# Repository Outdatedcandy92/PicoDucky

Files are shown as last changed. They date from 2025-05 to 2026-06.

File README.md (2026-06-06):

# PicoDucky V2.2

PicoDucky Version 2.2 is a minimalist, USB-stick-style RP2350 board designed for use as a security key or rubber ducky.

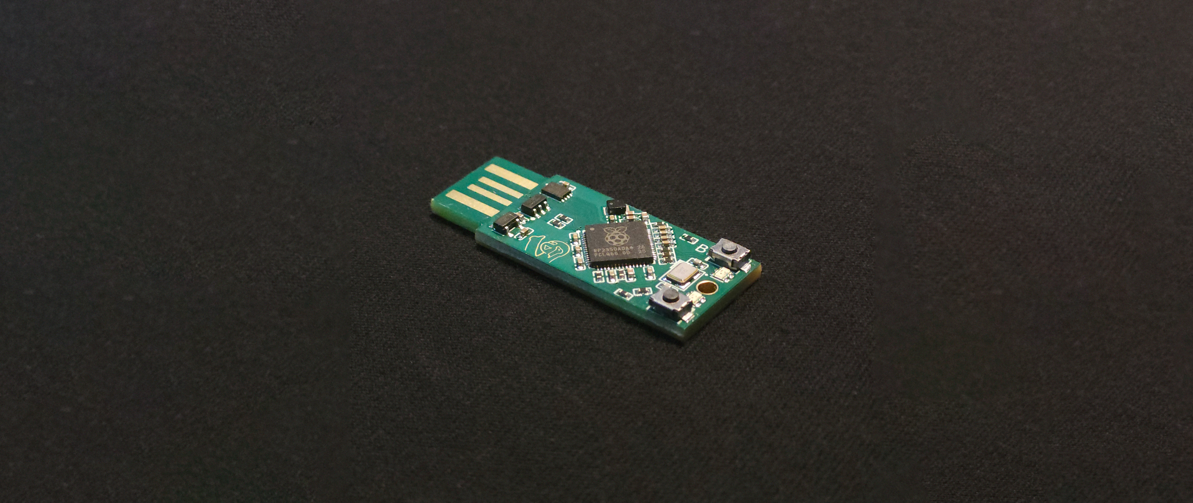
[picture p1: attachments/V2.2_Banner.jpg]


All source files for this board are located in `/src/V2.2`.

## Table of Contents

- [Overview](#picoducky-v2.2)
- [Quick Start](#quick-start)
- [Hardware](#hardware)
	- [Pinout](#pinout)
	- [Schematic](#schematic)
	- [PCB](#pcb)
	- [BOM/Reproduction](#bom/reproduction)
- [Firmware](#firmware)
- [Changelog](#changelog)
- [License](#license)

## Quick Start

To get started and use it as a security key
1. Hold the boot button on the board while plugging in the USB-C cable (the button has a `B` mark beside it).
2. The board will appear as a mass storage device.
3. Drag and drop the `picofido.uf2` file from `/firmware` onto the device.

The board will reboot, and the LEDs on the board should blink. It's now ready to be used as a FIDO security key.

You can head over to [webauthn.io](https://webauthn.io/) to test out your key.

Additional documentation can be found on [picoducky.rudymakes.com/docs](https://picoducky.rudymakes.com/docs)

## Hardware

### Pinout

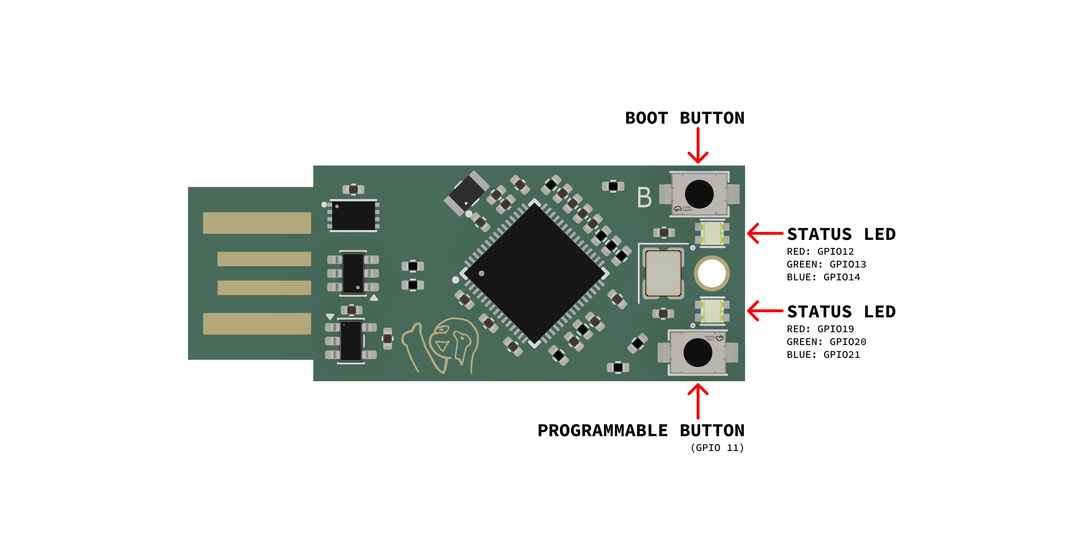
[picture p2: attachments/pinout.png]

### Schematic

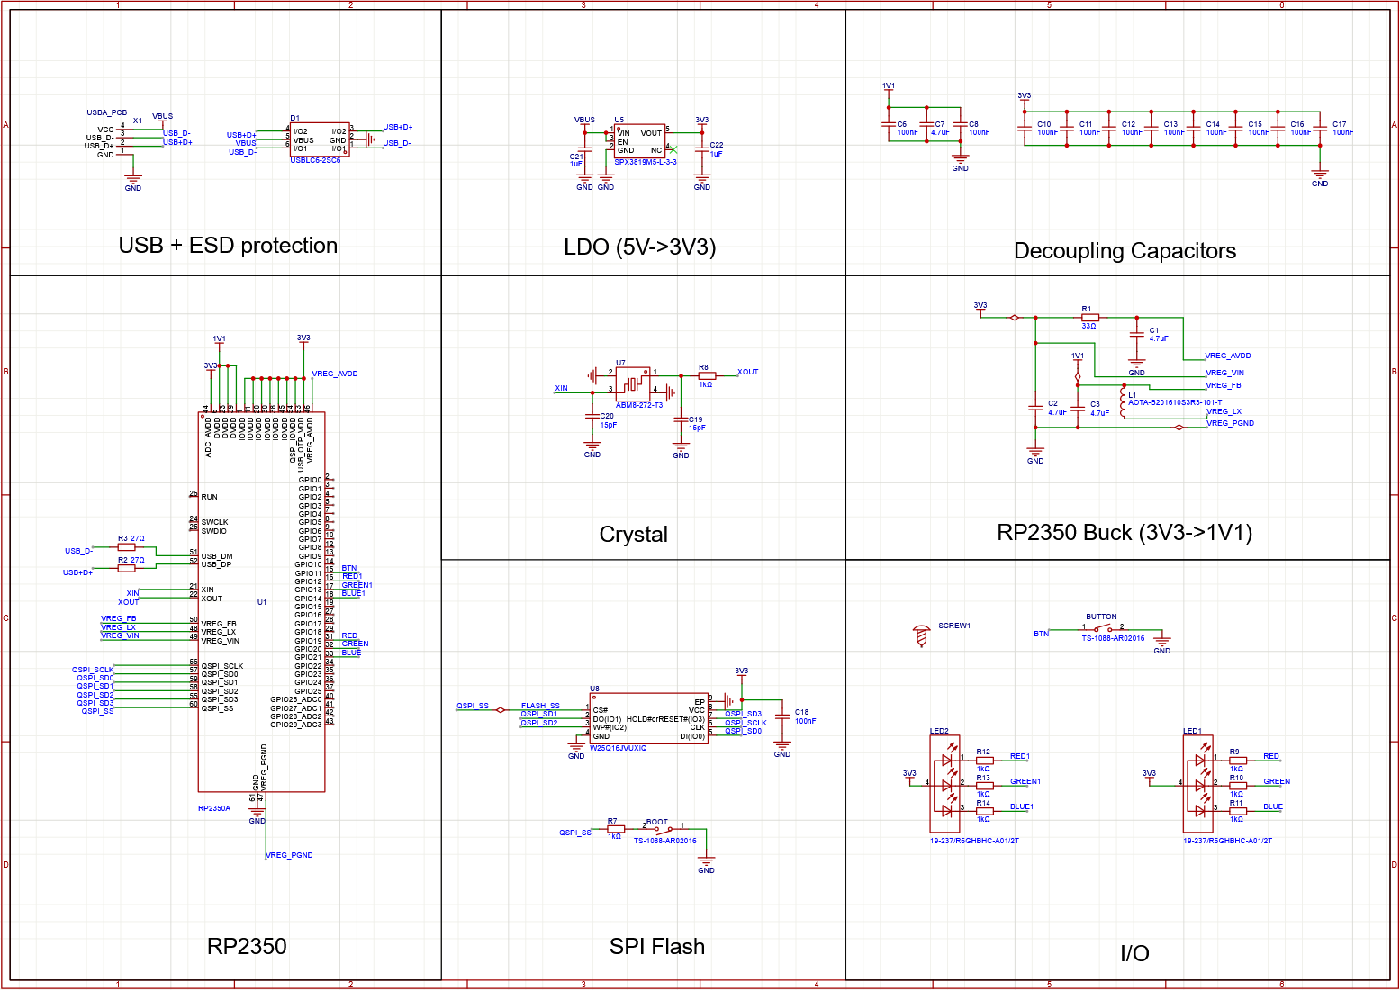
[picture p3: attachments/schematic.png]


### PCB

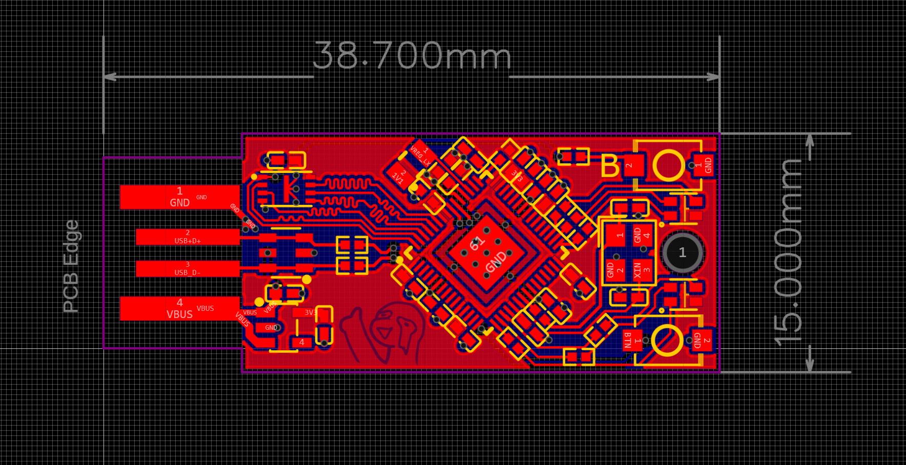
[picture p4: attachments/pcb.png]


### BOM/Reproduction

The BOM and gerber files can be found under `/hardware/{revision}/production`

If you plan on ordering the board make sure to set your board thickness to 2.0mm to ensure it fits snugly in a USB A port. Getting ENIG finish is also recommended as it doesn't oxidize and wears less over time.

Do note that having 2.0mm and ENIG together will lead to high setup fees from your PCB fab and will be expensive. For reference getting the minimum order quantity of 5 PCBs and 2 assembled PCBs from JLCPCB with 2.0mm thickness and ENIG costs around $100.

## Firmware

This board uses [Pico Fido](https://github.com/polhenarejos/pico-fido) by [Pol Henarejos](https://github.com/polhenarejos) with slight modifications such as updating the status LED pin number for the board.

## Changelog

#### V2.2
- Switched down the external flash from 8mb to 2mb to optimize cost
#### V2.1
- Switched down to a 8mb flash for smaller footprint
- Added a 2mm hole for keychains
- Switched back to using 2 RGB LEDs
- Optimized layout and routing compared to previous versions
#### V2.0
- Switched to the RP2350
- Used smaller SOT-23-5 LDO
- Switched to using 2 bigger buttons
- 1 Green Status LED
- Added ESD protection on USB lines
#### V1.0
First ever version
- Used the RP2040
- 16mb external flash
- Chonky SOT-223 footprint LDO
- 3 tiny buttons (very hard to click)
- 2 RBG LEDs

---
## License

This project is licensed under the CERN Open Hardware Licence Version 2 Weakly Reciprocal [(CERN OHL W)](LICENSE.txt)

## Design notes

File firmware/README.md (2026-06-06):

# PicoDucky Documentation

The `pico-fido` folder includes the source code for the modified version of PicoFIDO that the PicoDucky is running.

Additional documentation can be found on [picoducky.rudymakes.com/docs](https://picoducky.rudymakes.com/docs)

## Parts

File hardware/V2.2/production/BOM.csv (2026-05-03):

No. | Quantity | Footprint | Value | Device | LCSC Stock | LCSC Price | JLCPCB Stock | JLCPCB Price | Supplier Part | Manufacturer Part
1 | 1 | USBA_PCB |  | USBA_PCB |  | 2.6475
2 | 1 | SW-SMD_L3.9-W3.0-P4.45 |  | TS-1088-AR02016 |  |  | 582292 | 0.0083 | C720477 | TS-1088-AR02016
3 | 1 | C0402 | 4.7uF | CL05A475MP5NRNC |  |  | 2960347 | 0.0009 | C23733 | CL05A475MP5NRNC
4 | 1 | C0402 | 100nF | CL05B104KO5NNNC |  |  | 20013117 | 0.0002 | C1525 | CL05B104KO5NNNC
5 | 1 | C0402 | 1uF | CL05A105KA5NQNC |  |  | 8734328 | 0.0006 | C52923 | CL05A105KA5NQNC
6 | 1 | SOT-23-6_L2.9-W1.6-P0.95-LS2.8-BL |  | USBLC6-2SC6_C2687116 |  |  | 251847 | 0.0067 | C2687116 | USBLC6-2SC6
7 | 1 | IND-SMD_L2.0-W1.6_AOTA-B201610S3R3-101-T |  | AOTA-B201610S3R3-101-T |  |  | 9385 | 0.0424 | C42411119 | AOTA-B201610S3R3-101-T
8 | 1 | R0402 | 33Ω | 0402WGF330JTCE |  |  | 5209402 | 0.0002 | C25105 | 0402WGF330JTCE
9 | 1 | R0402 | 1kΩ | 0402WGF1001TCE |  |  | 12688834 | 0.0002 | C11702 | 0402WGF1001TCE
10 | 1 | SOT-23-5_L3.0-W1.6-P0.95-LS2.8-BR |  | SPX3819M5-L-3-3 |  |  | 66147 | 0.0157 | C20617301 | SPX3819M5-L-3-3
11 | 1 | QFN-60_L7.0-W7.0-P0.40-TL-EP3.4 |  | RP2350A_C42411118 |  |  | 3597 | 0.1854 | C42411118 | RP2350A
12 | 1 | C0402 | 15pF | 0402CG150J500NT |  |  | 1496521 | 0.0002 | C1548 | 0402CG150J500NT
13 | 1 | CRYSTAL-SMD_4P-L3.2-W2.5-BL |  | ABM8-272-T3_C20625731 |  |  | 13844 | 0.0431 | C20625731 | ABM8-272-T3
14 | 1 | LED-ARRAY-SMD_4P-L1.6-W1.6-BL_1 |  | 19-237/R6GHBHC-A01/2T |  |  | 41805 | 0.0093 | C60105 | 19-237/R6GHBHC-A01/2T
15 | 1 | Screw-Hole-M2 |  | Screw-Hole-M2 |  | 2.6475
16 | 1 | R0402 | 27Ω | 0402WGF270JTCE |  |  | 344663 | 0.0002 | C25100 | 0402WGF270JTCE
17 | 1 | USON-8_L3.0-W2.0-P0.50-BL-EP |  | W25Q16JVUXIQ |  |  | 2 | 0.1047 | C2843335 | W25Q16JVUXIQ

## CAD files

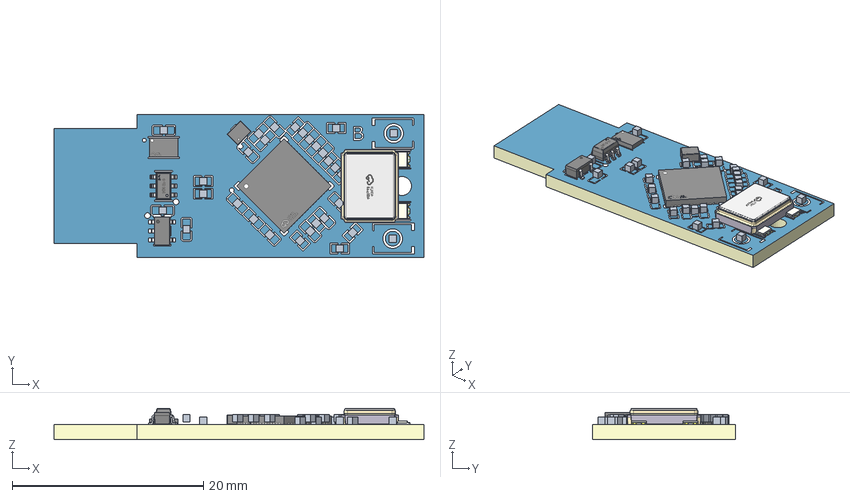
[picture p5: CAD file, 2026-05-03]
hardware/V2.2/CAD/3D.step
38.7 x 15.0 x 3.28 mm
Board~NZN2
TopCopper~NZN2
BottomCopper~NZN2
TopSilkscreen~NZN2
TopFpcStiffener~NZN2
BottomFpcStiffener~NZN2
SOT-23-6_L2.9-W1.6-P0.95-LS2.8-BL~SOT-23-6_ L2.9-W1.6-H1.5-LS2.8-P0.95~NZN2
CRYSTAL-SMD_4P-L3.2-W2.5-BL~CRYSTAL-SMD_4P-L3.2-W2.5-BL~NZN2
R3~R0402~R0402_L1.0-W0.5-H0.4~NZN2 x 11
BUTTON~SW-SMD_L3.9-W3.0-P4.45~SW-SMD_L3.9-W2.9-H2.0-LS4.8~NZN2 x 2
C20~C0402~C0402_L1.0-W0.5-H0.5~NZN2 x 19
LED-ARRAY-SMD_4P-L1.6-W1.6-BL_1~LED-ARRAY-SMD_4P-L1.6-W1.6_ EAST1616RGBB6~NZN2 x 2
SOT-23-5_L3.0-W1.6-P0.95-LS2.8-BR~SOT-23-5_ L3.0-W1.6-P0.95-LS2.8-BR~NZN2
USON-8_L3.0-W2.0-P0.50-BL-EP~USON-8_L2.0-W3.0-P0.50-TL-EP~NZN2
IND-SMD_L2.0-W1.6_AOTA-B201610S3R3-101-T~IND-SMD_L2.0-W1.6_ AOTA-B201610S3R3-101-T~NZN2
QFN-60_L7.0-W7.0-P0.40-TL-EP3.4~QFN-60_L7.0-W7.0-P0.40-TL-EP_ XU316-1024~NZN2

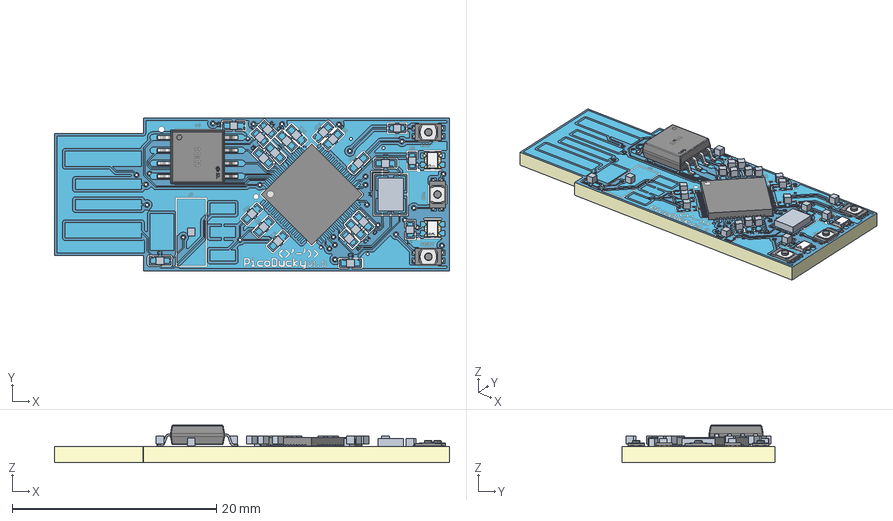
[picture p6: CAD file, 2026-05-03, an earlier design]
hardware/V1.0/CAD/PCB.step
38.7 x 15.0 x 3.68 mm
Board~82VG
TopCopper~82VG
BottomCopper~82VG
TopSilkscreen~82VG
TopFpcStiffener~82VG
BottomFpcStiffener~82VG
R7~R0402~R0402_L1.0-W0.5-H0.4~82VG x 6
C8~C0402~C0402_L1.0-W0.5-H0.5~82VG x 16
CRYSTAL-SMD_4P-L3.2-W2.5-BL~CRYSTAL-SMD_4P-L3.2-W2.5-BL~82VG
SOT-223-3_L6.5-W3.4-P2.30-LS7.0-BR~SOT-223-4P_ L6.5-W3.5-H1.6-LS7.0-P2.30~82VG
SW-SMD_4P-L2.6-W1.6-P0.75-LS3.0~SW-SMD_4P-L2.6-W1.6-P0.75-LS3.0~82VG x 3
LED-ARRAY-SMD_4P-L1.6-W1.6-BL-CW~LED-SMD-4P_L1.6-W1.6-H0.4-LS1.6~82VG x 2
SOIC-8_L5.3-W5.3-P1.27-LS8.0-BL~SOIC-8_L5.3-W5.3-H1.9-LS7.9-P1.27~82VG
LQFN-56_L7.0-W7.0-P0.4-EP~QFN-56_L7.0-W7.0-P0.40-TL-EP4.0~82VG

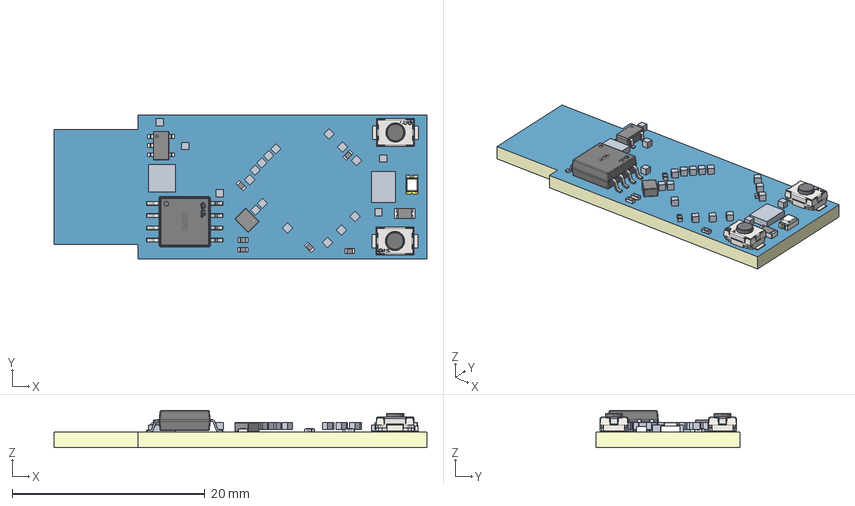
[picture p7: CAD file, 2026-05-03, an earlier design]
hardware/V2.0/CAD/3D.step
38.7 x 15.0 x 3.85 mm
Board~88uZ
TopCopper~88uZ
BottomCopper~88uZ
TopFpcStiffener~88uZ
BottomFpcStiffener~88uZ
C22~C0402~C0402_L1.0-W0.5-H0.5~88uZ x 19
LED0805-R-RD~LED0805-RD~88uZ
R0603~R0603~88uZ
SOT-23-6_L2.9-W1.6-P0.95-LS2.8-BL~SOT-23-6_ L2.9-W1.6-H1.5-LS2.8-P0.95~88uZ
CRYSTAL-SMD_4P-L3.2-W2.5-BL~CRYSTAL-SMD_4P-L3.2-W2.5-BL~88uZ
IND-SMD_L2.0-W1.6_AOTA-B201610S3R3-101-T~IND-SMD_L2.0-W1.6_ AOTA-B201610S3R3-101-T~88uZ
SW-SMD_L3.9-W3.0-P4.45~SW-SMD_L3.9-W2.9-H2.0-LS4.8~88uZ x 2
R0402~R0402_L1.0-W0.5-H0.4~88uZ x 6
SOT-23-5_L3.0-W1.6-P0.95-LS2.8-BR~SOT-23-5_ L3.0-W1.6-P0.95-LS2.8-BR~88uZ
SOP-8_L5.3-W5.3-P1.27-LS8.0-BL~SOP-8_L5.2-W5.3-H2.1-LS7.9-P1.27~88uZ

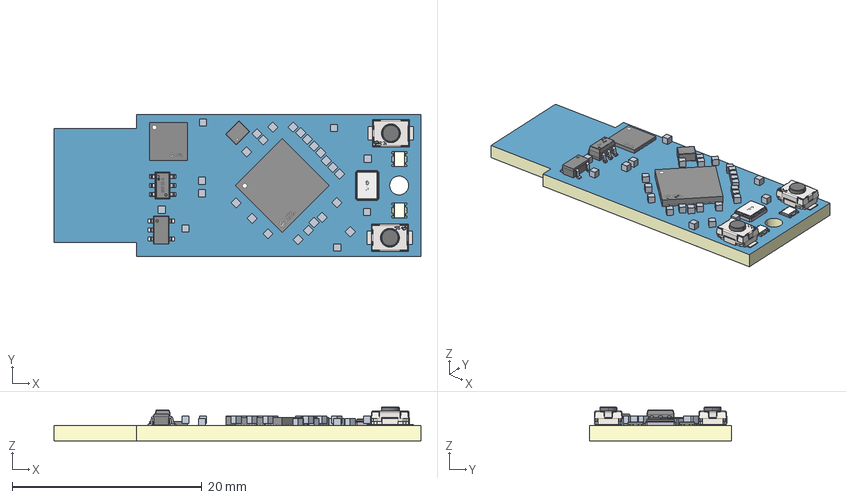
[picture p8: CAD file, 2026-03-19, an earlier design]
hardware/V2.1/CAD/3D.step
38.7 x 15.0 x 3.55 mm
Board~sNAA
TopCopper~sNAA
BottomCopper~sNAA
TopFpcStiffener~sNAA
BottomFpcStiffener~sNAA
SW-SMD_L3.9-W3.0-P4.45~SW-SMD_L3.9-W2.9-H2.0-LS4.8~sNAA x 2
C20~C0402~C0402_L1.0-W0.5-H0.5~sNAA x 19
R3~R0402~R0402_L1.0-W0.5-H0.4~sNAA x 11
SOT-23-6_L2.9-W1.6-P0.95-LS2.8-BL~SOT-23-6_ L2.9-W1.6-H1.5-LS2.8-P0.95~sNAA
IND-SMD_L2.0-W1.6_AOTA-B201610S3R3-101-T~IND-SMD_L2.0-W1.6_ AOTA-B201610S3R3-101-T~sNAA
XSON-8_L4.0-W4.0-P0.80-TL-EP~XSON-8_L4.0-W4.0-P0.80-TL-EP~sNAA
LED-ARRAY-SMD_4P-L1.6-W1.6-BL_1~LED-ARRAY-SMD_4P-L1.6-W1.6_ EAST1616RGBB6~sNAA x 2
CRYSTAL-SMD_4P-L3.2-W2.5-BL~CRYSTAL-SMD_4P-L3.2-W2.5-BL~sNAA
QFN-60_L7.0-W7.0-P0.40-TL-EP3.4~QFN-60_L7.0-W7.0-P0.40-TL-EP_ XU316-1024~sNAA
SOT-23-5_L3.0-W1.6-P0.95-LS2.8-BR~SOT-23-5_ L3.0-W1.6-P0.95-LS2.8-BR~sNAA

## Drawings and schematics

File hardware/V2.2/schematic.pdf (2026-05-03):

USB + ESD protection | LDO (5V->3V3) | Decoupling Capacitors

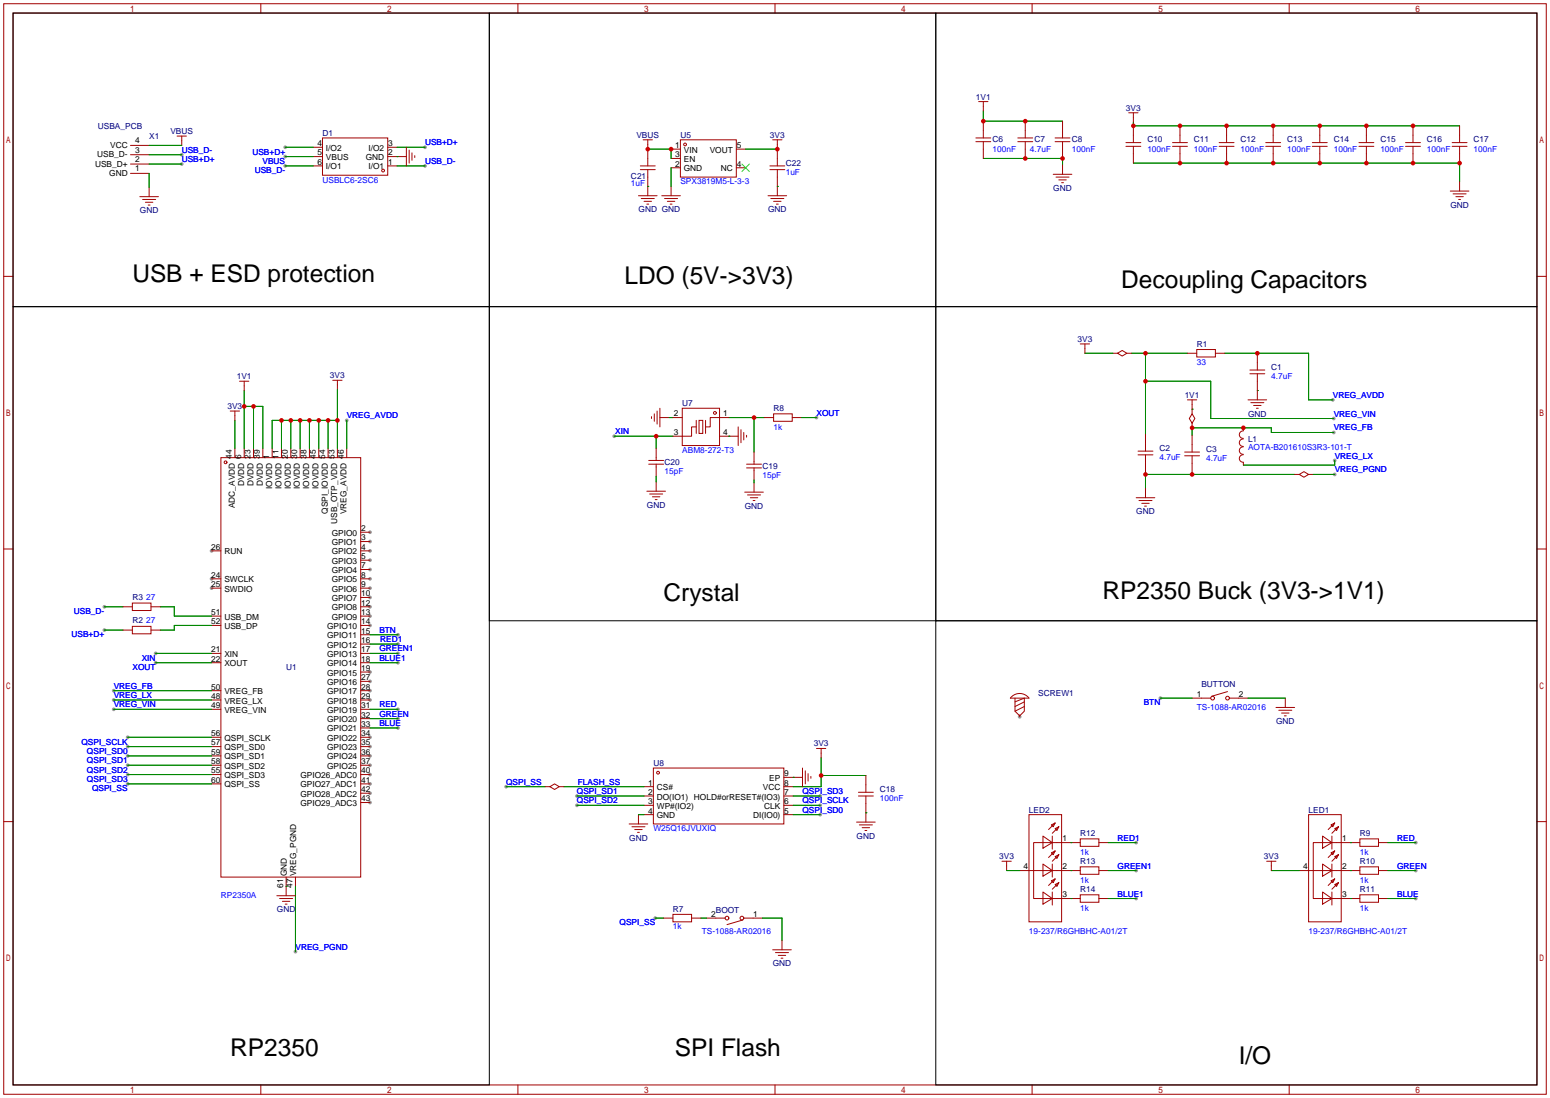
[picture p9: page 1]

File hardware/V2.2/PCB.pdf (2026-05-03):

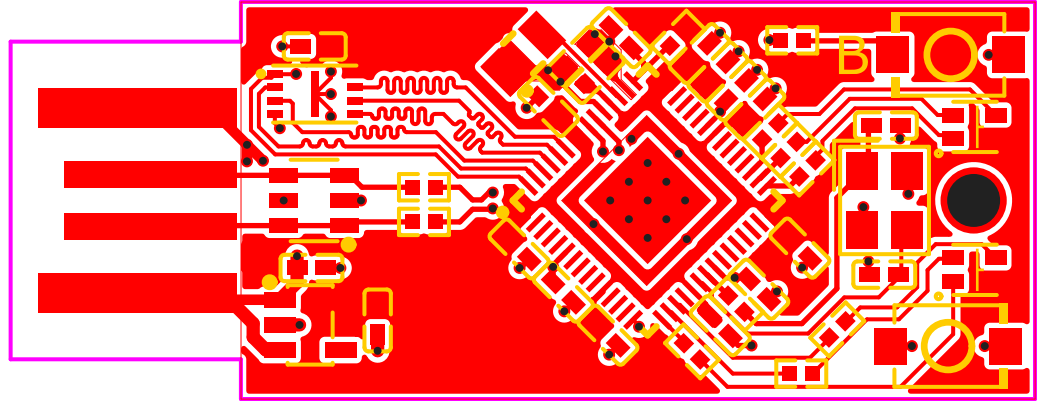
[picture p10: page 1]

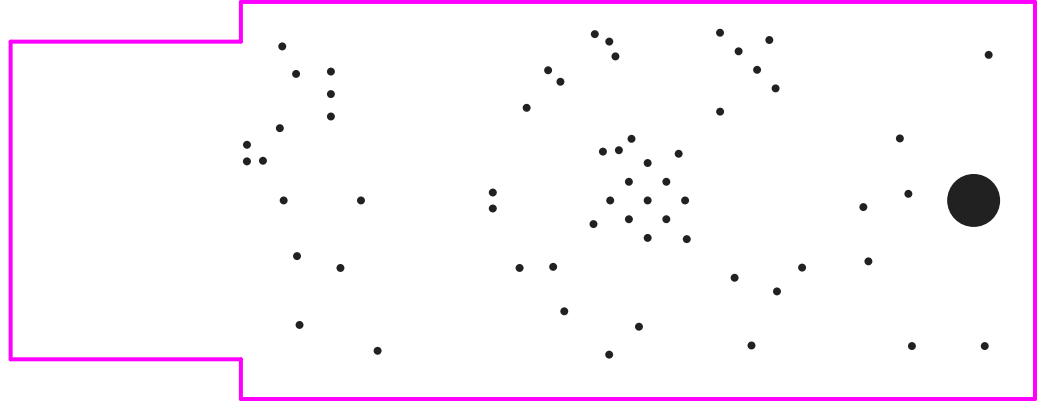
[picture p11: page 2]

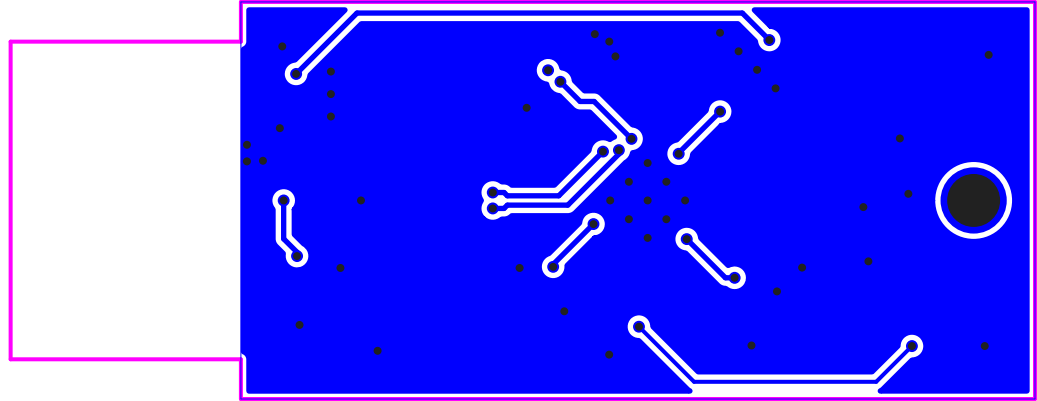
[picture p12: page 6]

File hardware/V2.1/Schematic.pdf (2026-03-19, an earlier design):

USB + ESD protection | LDO (5V->3V3) | Decoupling Capacitors

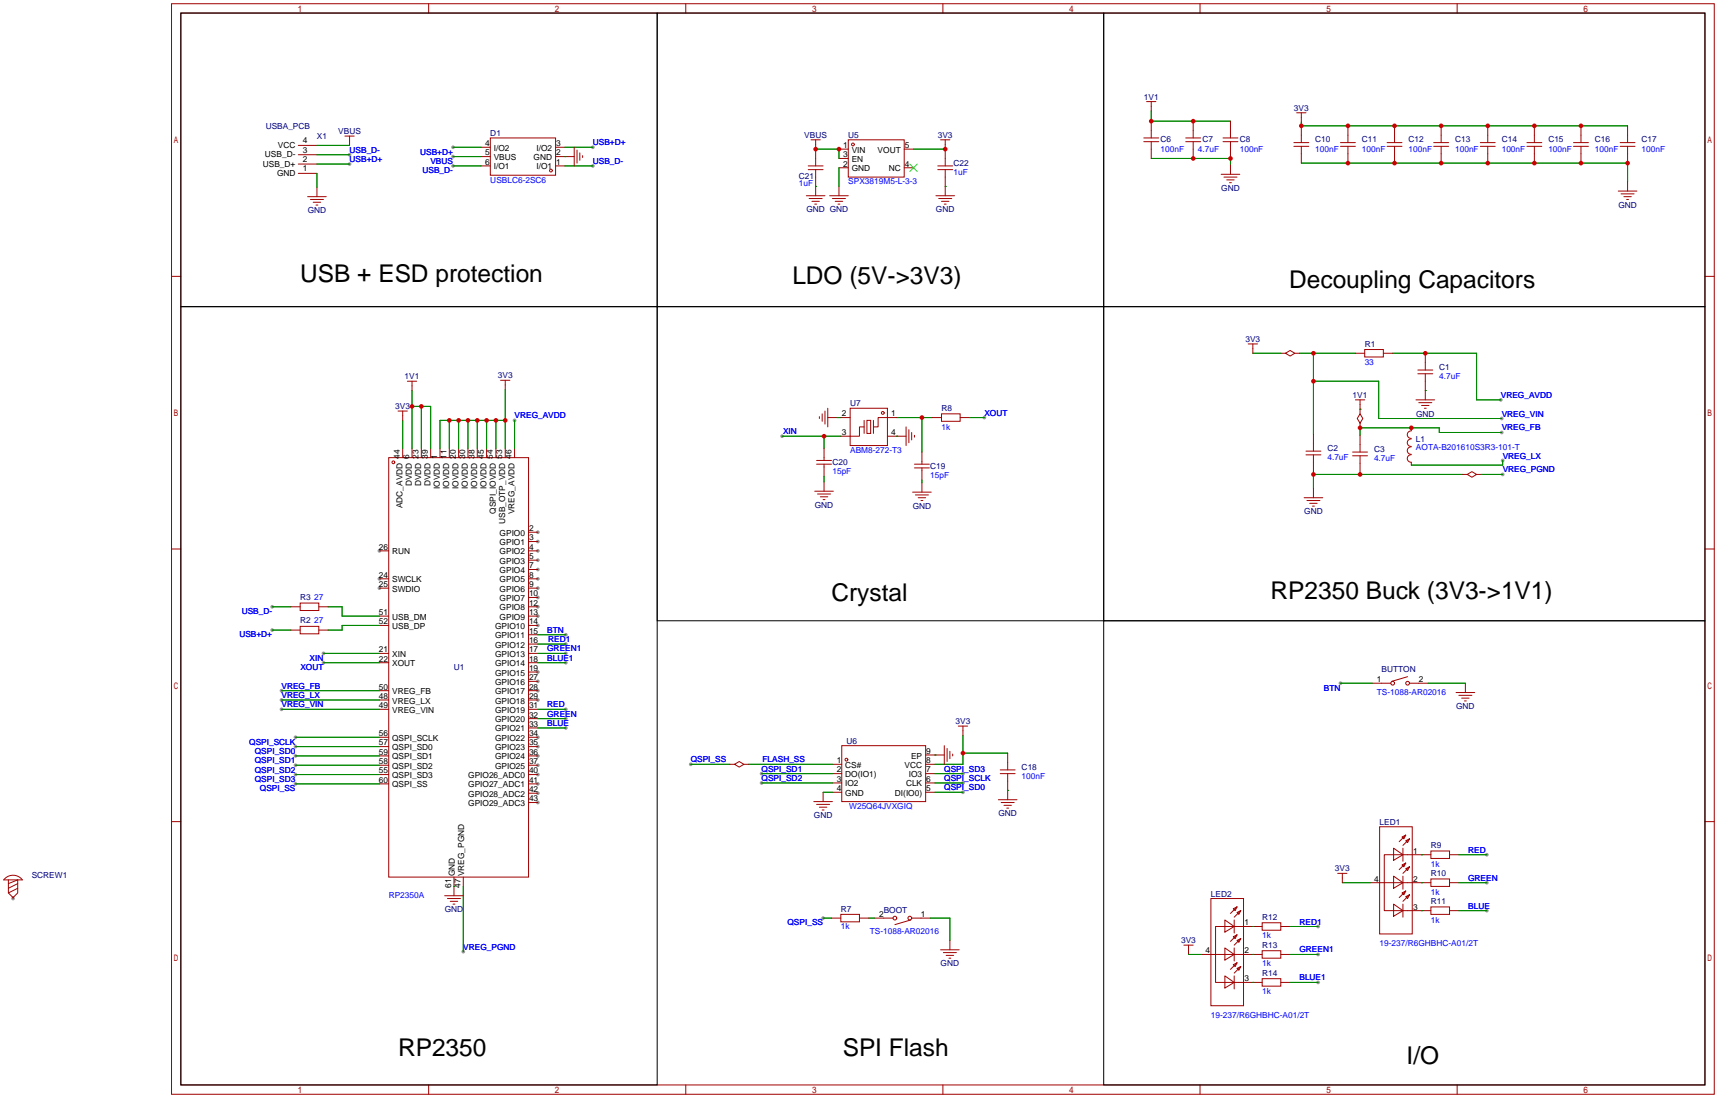
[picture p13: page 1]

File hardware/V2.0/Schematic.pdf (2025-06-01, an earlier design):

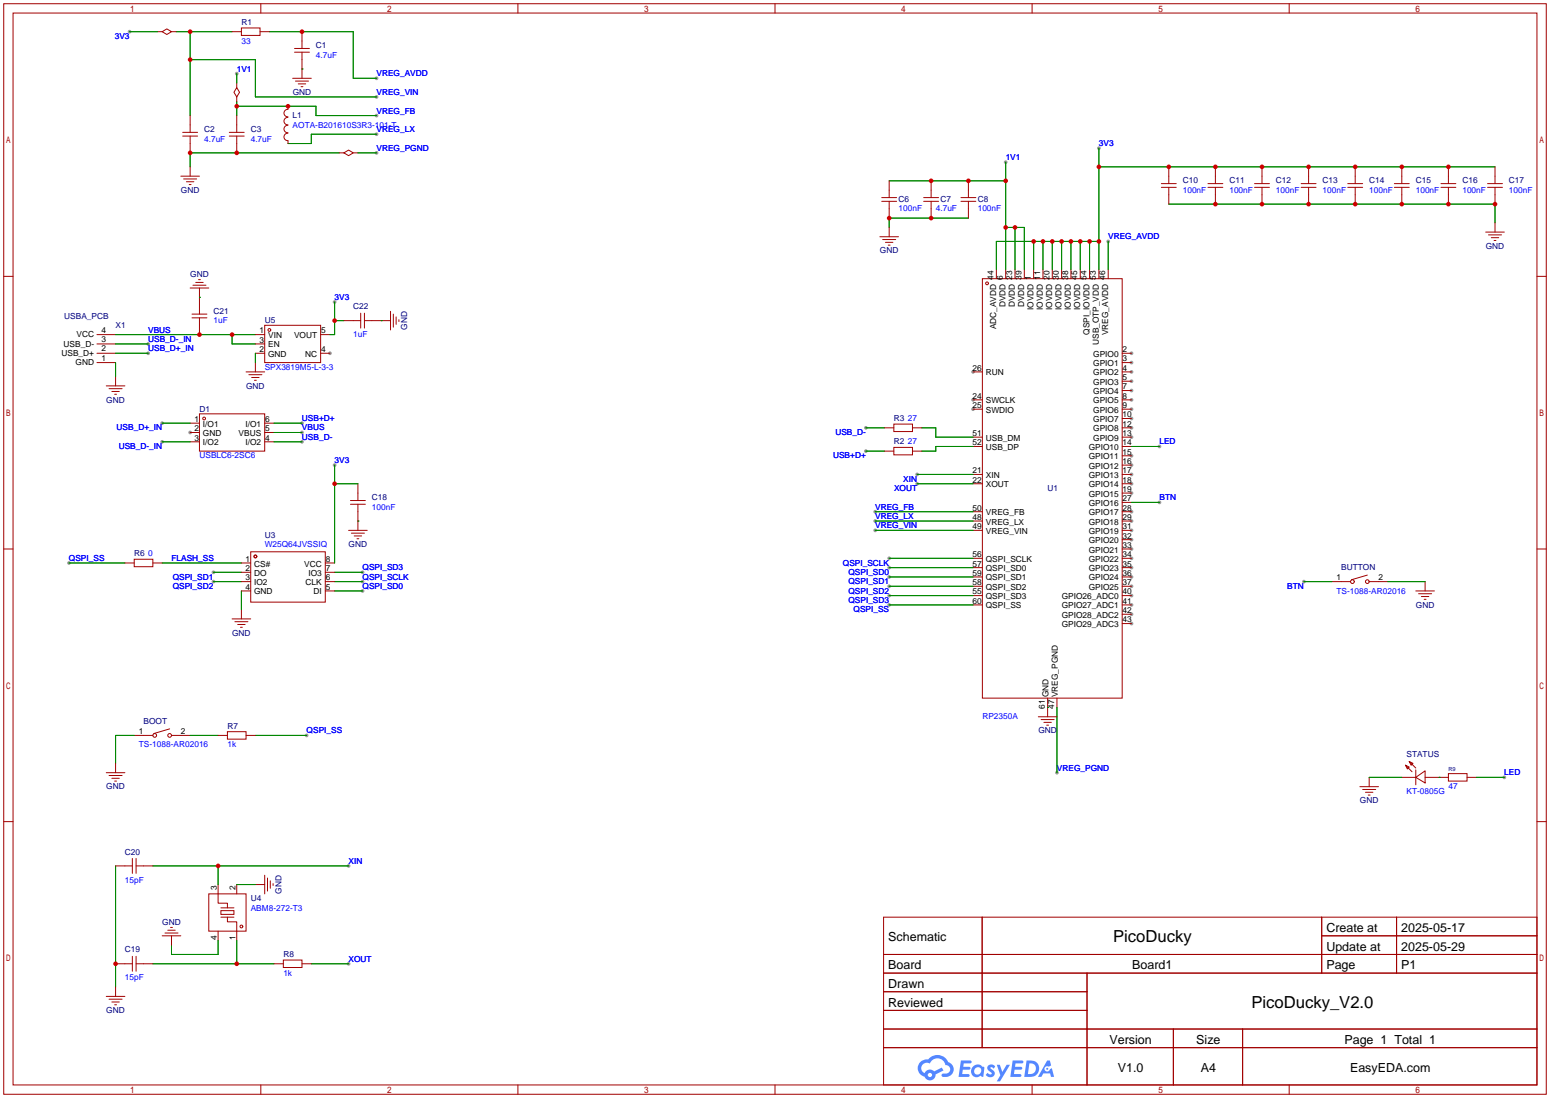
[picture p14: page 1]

Schematic | PicoDucky | Create at | 2025-05-17

Update at | 2025-05-29

Board | Board1 | Page | P1
Drawn | | PicoDucky_V2.0
Reviewed

Version | Size | Page 1 Total 1
V1.0 | A4 | EasyEDA.com

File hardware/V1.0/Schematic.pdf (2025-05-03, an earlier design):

# GNDVCC

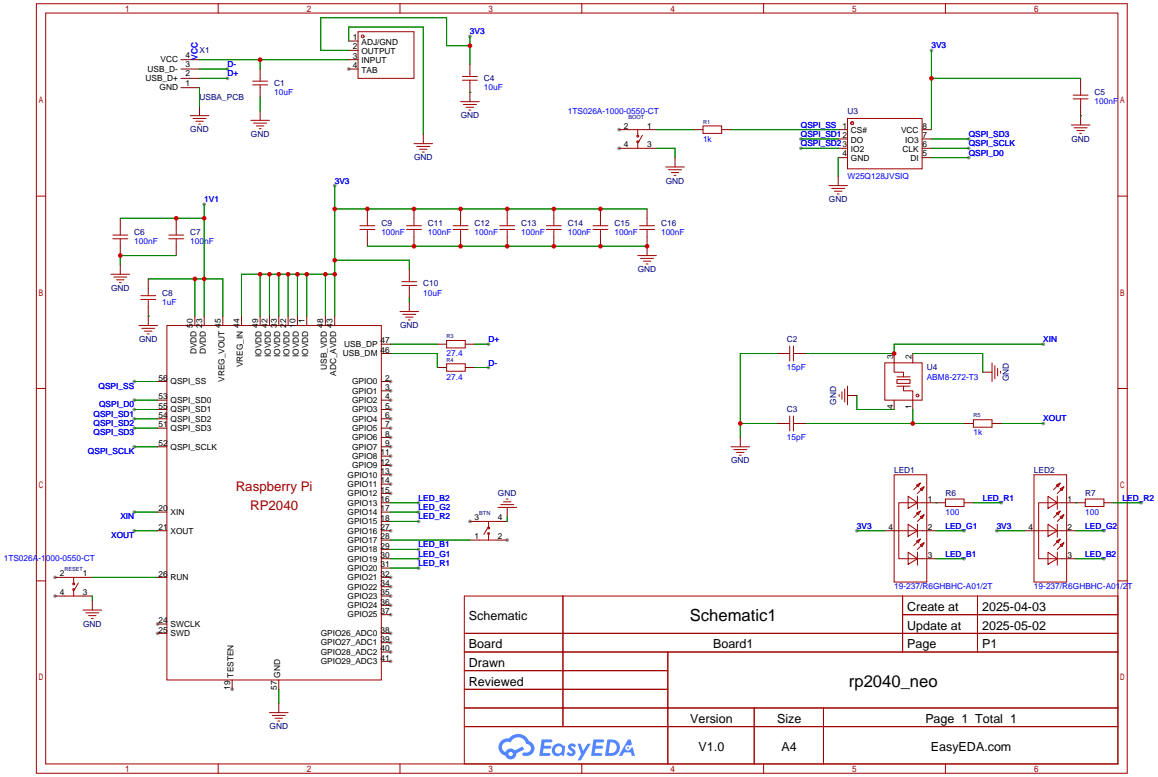
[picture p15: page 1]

Schematic | Schematic1 | Create at | 2025-04-03

Update at | 2025-05-02

Board | Board1 | Page | P1
Drawn | | rp2040_neo
Reviewed

Version | Size | Page 1 Total 1
V1.0 | A4 | EasyEDA.com

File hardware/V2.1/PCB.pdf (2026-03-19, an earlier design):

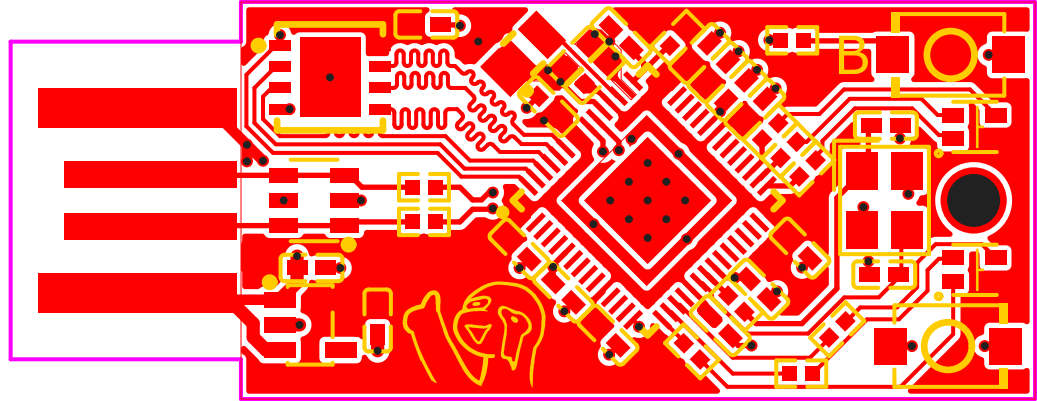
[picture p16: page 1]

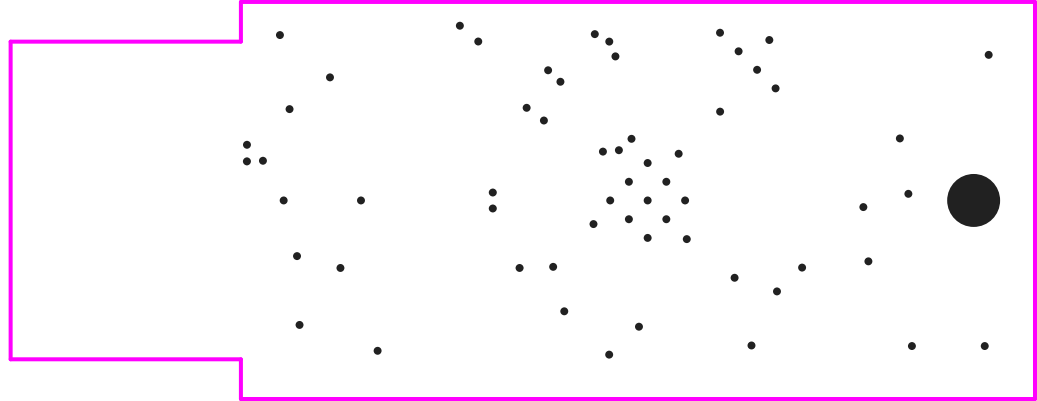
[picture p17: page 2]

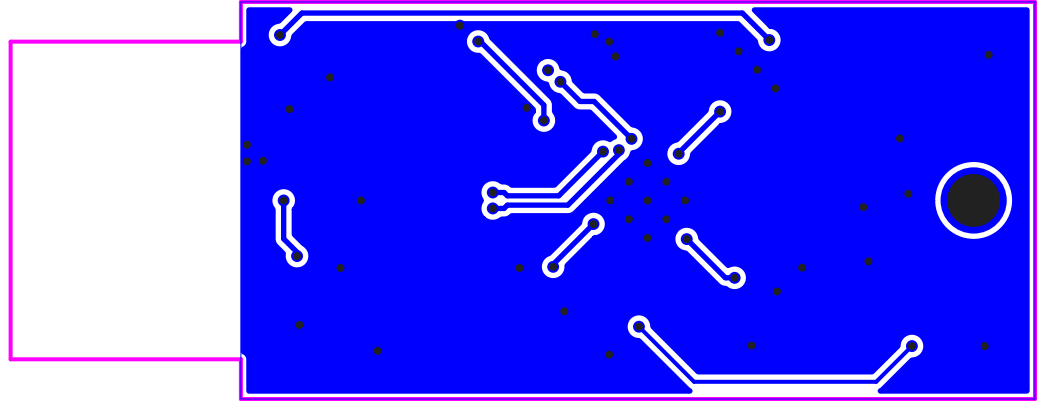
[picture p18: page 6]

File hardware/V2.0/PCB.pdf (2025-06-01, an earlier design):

(>'-')>
R7R8

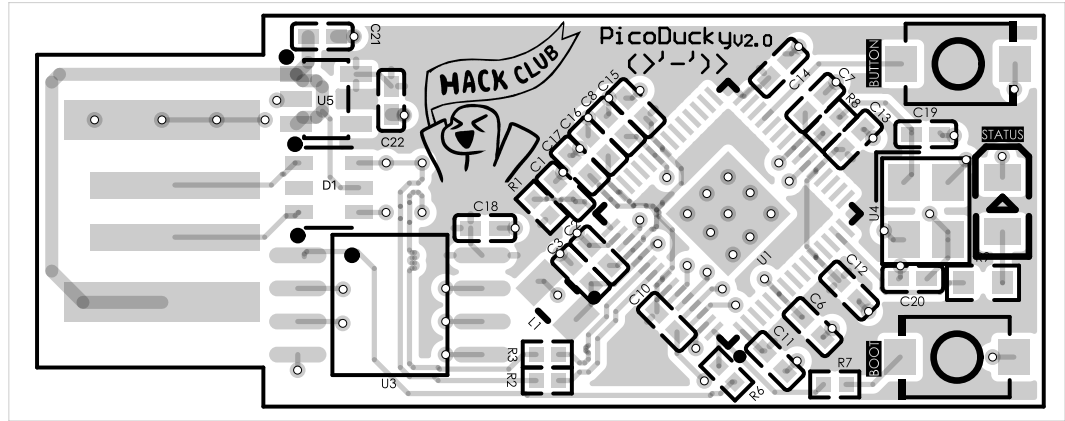
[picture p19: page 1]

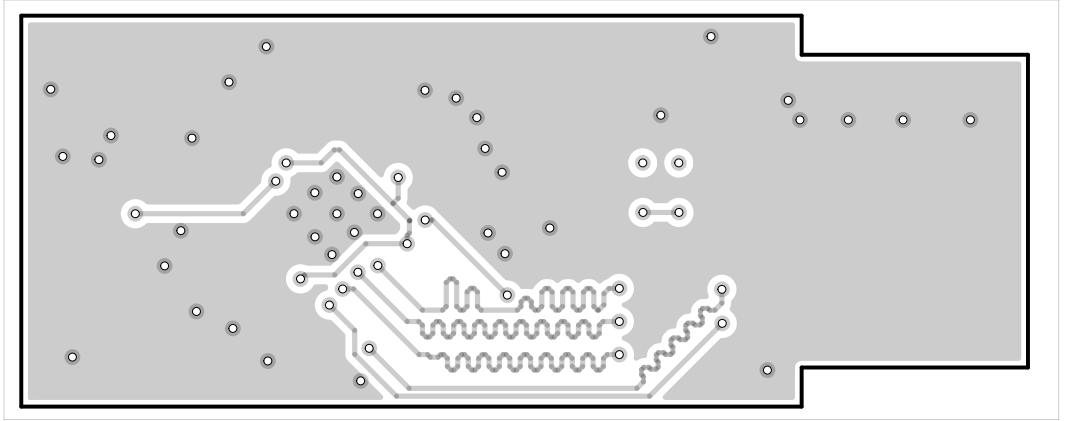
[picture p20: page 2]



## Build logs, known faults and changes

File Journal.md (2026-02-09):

# Picoducky V2

## What am I making?
I'm building a compact USB device based on the RP2350 Chip. The goal is to create a minimalist, plug and play board that connects directly to USB-A ports and acts as a HID device, or a FIDO security key (using PicoFido).
This is the second iteration of the project. Version 1 used a RP2040 and worked well overall, but there were a few issues, like the buttons being too small and hard to press without using your nails, and the board slipping out of the usb board (Not really a design fault, I ordered 1.6mm thick pcb to save on cost for the first prototype).

### My Goals For This Project
- [ ] RP2350 MCU
- [ ] Same Size As Version 1
- [ ] Bigger Buttons
- [ ] Plugs In Directly (2.0mm Thickness)
- [ ] Cool silkscreen art

## Total Time Spent: 13 Hours

# 25th May - Schematic And Rough PCB Layout

Since I already made a board using a RP2040, remaking it using a RP2350 wasn't that difficult. There were a few new things I had to take into consideration like a new circuit for the voltage regulator but other wise it was mostly the same. [RP2350 Hardware Design Guide](https://datasheets.raspberrypi.com/rp2350/hardware-design-with-rp2350.pdf) 

Now for this version I decided to spend more time on finding cheap components that were in JLCPCB's basic library. This probably took more time than making the actual schematic, but in the end the BOM was a lot more optimized than V1, I did decide to not switch out the inductor for a cheaper one because the RP2350 guide suggested it worked best with those ones. For its ldo I went with the one the guide recommended which supplies around 1A and for the flash I also went with what the guide suggested but I just used the 8mb version instead of the 16mb.

After this I moved onto designing the PCB, I usually start by making a very rough layout of where the components will be to get a rough estimate of how much space its gonna take.

**Layout Version 1** : The board was around 3 mm wider in order to fit the new voltage regulator circuitry.


I did not like Version 1 of the layout because it had a larger footprint than PicoDuckyV1. Plus there was a lot of empty space on the board meaning this all could be compressed down into the original footprint of the V1 (15x30mm).

**Layout Version 2** : Starting to look more like what I want



I flipped the RP2350 90 Degrees counterclockwise and now everything fits nicely into the footprint of the original board (15x30mm). Also switched out the places of ldo and flash storage.

### Time Spent: 6 Hours

# 26th May - Initial Routing

Started routing the board today. I first start off with the flash traces because I had to length tune them and ensure they were all almost the same length which took A LOT of time !!! . This was a major improvement over Version 1 of the PicoDucky which had its trace lengths mismatched by a lot (~20mm). The Data pins were also routed as a differential pair and were almost the same length.

*Flash Traces*


*More Routing*


### Time Spent: 2 Hours
# 27th May - Routing and Silkscreen

Finished Routing all the traces. It was a pretty boring process but here are the results.

*Finished Routing*



Also added some multicolored silkscreen!!




### Time Spent: 3 Hours
# May 29 - Improvements

I was using the AMS1117-3.3 as the LDO which provides up to 1A of current but also takes up a lot of space on the board. Since I don't have any GPIO pins on the board, supplying 1A would be pretty overkill and useless. My plan is to use a smaller LDO which can provide up to 500mA and then also add a ESD protection diode.




After switching to a smaller LDO I feel like there is too much free space on the board, I'm contemplating switch back to the SOT-23 package for the LDO.

### Time Spent: 2 Hours

# Sometime in June 

I recieved my board!! and phew it worked first try, everything worked, nothing was shorted, it looked beautiful with ENIG.

For testing out the firmware on it I went and used https://www.picokeys.com/pico-fido/ and installed it on my picoducky and then checked it on webauthn.io

I got PCBA so no assembly pics :p 

heres the final pcb image



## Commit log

2025-05-03 version 1
    [BOM.csv, PickAndPlace.xlsx]
2025-10-21 Add Getting Started guide for PicoDucky
    Added a comprehensive Getting Started guide for PicoDucky, including installation steps for CircuitPython, library installation, basic HID examples, RGB LED usage, and additional resources.
2025-10-21 Refactor PicoDucky demo for better organization
    Refactor PicoDucky demo code to improve structure and readability, including LED setup and HID device initialization.
2026-06-06 Add pico-fido as submodule
